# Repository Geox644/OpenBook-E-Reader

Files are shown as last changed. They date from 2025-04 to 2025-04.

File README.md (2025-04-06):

# OpenBook Reader
<br>
Proiectul consta in realizarea unui E-Book Reader accesibil, cu un ecran ce imita hartia, special pentru a avea un consum redus de energie, dar si pentru a oferi utilizatorului o excperinta cat mai placuta. Dispozitivul a fost proiectat de la zero: crearea schemei electrice cu componentele hardware, realizarea 2D PCB + procesul de rutare, trecerea in plan 3D.

<br>

## Diagrama Bloc
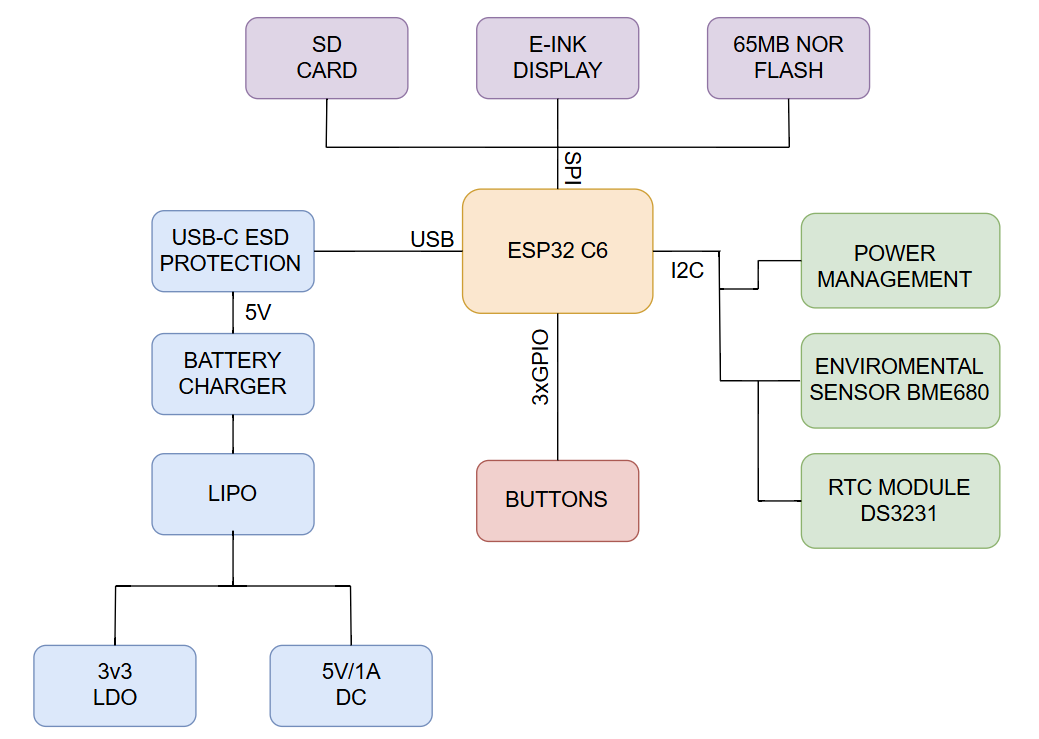
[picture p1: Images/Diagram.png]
Diagrama bloc


<br>

## Descriere functionalitati hardware

### ESP32-C6

* Rol: ESP32-C6 este microcontroller-ul, practic creierul dispozitivului care controleaza toate componentele, gestioneaza si datele.
* Arhitectura: RISC-V 32-bit
* Protocoale: GPIO, I2C, UART, SPI,  PWM
* Memorie:  SD + Flash
* Consum: 10mA (idle), 200mA (WiFi activat)

### MAX17048

* Rol: MAX17048 este monitorul bateriei care vede in timp real nivelul bateriei LiPo si procentul de încarcare.
* Protocol: I2C, SCL: IO6, SDA: IO7

### MCP73831

* Rol: Controloeaza incarcarea eficienta acumulatorul LiPo prin port-ul USB.
* Capacitate: ~500 mA

### XC6204

* Rol: XC6204 reprezinta regulator-ul LDO care reduce tensiunea de la 5V la 3.3V pentru alimentarea sigura a componentelor.

### RTC – DS3231

* Rol: Tine ora exacta chiar si fara alimentare, pentru afisarea corecta a timpului.
* Protocol: I2C, SCL: IO6, SDA: IO7
* Consum: 0.15mA

### BME688 SENSOR

* Rol: Masoara temperatura, umiditatea, etc.
* Protocol: I2C, SCL: IO6, SDA: IO7
* Consum: 3.1mA

### Card SD

* Rol: Salvarea datelor pe dispozitiv.
* Protocol: SPI (pini IO18–IO22)
* Consum: 50mA

### W25Q512JV

* Rol: W25Q512JV este memoria Flash care stocheaza resurse statice folosite de sistemul dispozitivului.
* Protocol: SPI (pini IO18–IO21)
* Consum: 25mA

### Butoane

* Rol: Permite interactiunea manuala a utilizatorului cu dispozitivul.
* Exista 3 tipuri de butoane (Reset, Boot, Change)
* Protocol: GPIO

### E-INK DISPLAY

* Rol: Afisarea continutului/informatiilor de pe dispozitiv. Are un consum redus, deoarece foloseste putine semnale, curentul este necesar atunci cand imaginea se schimba si ramane afisata fara alimentare continua.
* Protocol: GPIO, SPI
* Consum: 40mA

  <br>

## Interfete si pinii de comunicare

| Componente | Interfete | Pini ESP32-C6 |
|---|---|---|
| I2C | BME688, RTC, Battery | SDA (IO22), SCL (IO21) |
| SPI | SD Card, E-paper, NOR Flash | SCK (IO6), MOSI (IO7), MISO (IO2) |
| GPIO | Buttons | IO0 - IO23 |
| USB | Conectare alte dispozitive / incarcare | USB_D+/D- (IO13/IO12) |

<br>

## Observatii

* Modelul 3D al TP-urilor a fost realizat manual de catre mine si au fost pizitionate pe marginea placutei, cat mai aproape de componentele cu care aveau lagaturi
* Au fost facute modificari de footprint pentru U4 – MAX17048G+T10, deoarece alimentarea VBAT a fost proiectata cu o latime de 0.3mm, iar footprint-ul avea o latime a pinilor de 0.27mm.
* Componentele, dimensiunile si pozitiile acestora respecta cat de mult se poate design-ul de referinta.
* ~140 vias PCB
  
<br>

## Bill Of Materials (BOM)

| Componenta | Link | Datasheet |
|---|---|---|
| CAPACITOR 0402 | [Model](https://componentsearchengine.com/part-view/CC0402MRX5R5BB106/YAGEO) | [Datasheet](https://componentsearchengine.com/Datasheets/2/CC0402MRX5R5BB106.pdf) |
| Capacitor 0805| [Model](https://ro.mouser.com/ProductDetail/KYOCERA-AVX/SD0805S020S1R0?qs=jCA%252BPfw4LHbpkAoSnwrdjw%3D%3D) | [Datasheet](https://ro.mouser.com/datasheet/2/40/schottky-3165252.pdf) |
| CPH3225A | [Model](https://www.snapeda.com/parts/CPH3225A/Seiko+Instruments/view-part/?ref=eda) | [Datasheet](https://www.snapeda.com/parts/CPH3225A/Seiko+Instruments/view-part/?ref=eda) |
| RCL CPOL 3528 | [Model](https://www.snapeda.com/parts/TAJB475K025RNJ/AVX/view-part/?ref=dk&t=capacitor%203528&con_ref=None) | [Datasheet](https://s3.amazonaws.com/snapeda/datasheet/TAJB475K025RNJ_AVX.pdf) |
| Resistor 0402 | [Model](https://componentsearchengine.com/part-view/R0402%201%25%20100%20K%20(RC0402FR-07100KL)/YAGEO) | [Datasheet](https://www.yageo.com/upload/media/product/products/datasheet/rchip/PYu-RC_Group_51_RoHS_L_12.pdf) |
| MBR0530 DIODE | [Model](https://eu.mouser.com/ProductDetail/KYOCERA-AVX/SD0805S020S1R0?qs=jCA%252BPfw4LHbpkAoSnwrdjw%3D%3D) | [Datasheet](https://ro.mouser.com/datasheet/2/40/schottky-3165252.pdf) |
| PGB1010603MR DIODE | [Model](https://www.snapeda.com/parts/PGB1010603MR/Littelfuse/view-part/?ref=eda) | [Datasheet](https://www.snapeda.com/parts/PGB1010603MR/Littelfuse%20Inc./datasheet/) |
| BUTTON | [Model](https://industry.panasonic.com/global/en/products/control/switch/light-touch/number/evqpuj02k) | [Datasheet](https://industry.panasonic.com/global/en/downloads?tab=catalog&small_g_cd=203&part_no=EVQPUJ02K) |
| LED 0603 | [Model](https://www.snapeda.com/parts/KP-1608SURCK/Kingbright/view-part/?ref=search&t=LED%200603) | [Datasheet](https://www.snapeda.com/parts/KP-1608SURCK/Kingbright/datasheet/) |
| BME680 Sensor | [Model](https://www.digikey.ro/en/models/7401317) | [Datasheet](https://www.bosch-sensortec.com/media/boschsensortec/downloads/datasheets/bst-bme680-ds001.pdf) |
| SJ | [Model](https://grabcad.com/library/solder-jumpers-1) | [Datasheet](https://grabcad.com/library/solder-jumpers-1) |
| ESP32C6 Varistor 1812 (PFMF) | [Model](https://ro.mouser.com/ProductDetail/EPCOS-TDK/B72520T0350K062?qs=dEfas%2FXlABIszF52uu7vrg%3D%3D) | [Datasheet](https://www.snapeda.com/parts/RC0603JR-070RL/Yageo/datasheet/) |
| FH34SRJ-24S-0.5SH (J1) | [Model](https://www.snapeda.com/parts/FH34SRJ-24S-0.5SH(99)/Hirose/view-part/) | [Datasheet](https://www.snapeda.com/parts/FH34SRJ-24S-0.5SH(99)/Hirose%20Connector/datasheet/) |
| USB4110-GF-A (J2) | [Model](https://componentsearchengine.com/part-view/USB4110-GF-A/GCT%20(GLOBAL%20CONNECTOR%20TECHNOLOGY)) | [Datasheet](https://gct.co/files/drawings/usb4110.pdf) |
| QWIIC Connector (J3) | [Model](https://www.snapeda.com/parts/PRT-14417/SparkFun/view-part/) | [Datasheet](https://www.snapeda.com/parts/PRT-14417/SparkFun%20Electronics/datasheet/) |
| 112A-TAAR-R03 (J4)| [Model](https://www.snapeda.com/parts/112A-TAAR-R03/Attend/view-part/) | [Datasheet](https://www.snapeda.com/parts/112A-TAAR-R03/Attend/datasheet/) |
| 744043680 (L1)| [Model](https://ro.mouser.com/ProductDetail/Wurth-Elektronik/744043680?qs=PGXP4M47uW6VkZq%252BkzjrHA%3D%3D) | [Datasheet](https://www.we-online.com/components/products/datasheet/744043680.pdf) |
| DMG2305UX-7 (Q1&Q2) | [Model](https://componentsearchengine.com/part-view/DMG2305UX-7/Diodes%20Incorporated) | [Datasheet](https://www.snapeda.com/parts/SI1308EDL-T1-GE3/Vishay%20Siliconix/datasheet/) |
| SI1308EDL-T1-GE3 (Q3) | [Model](https://componentsearchengine.com/part-view/SI1308EDL-T1-GE3/Vishay) | [Datasheet](https://www.snapeda.com/parts/SI1308EDL-T1-GE3/Vishay%20Siliconix/datasheet/) |
| W25Q512JVEIQ (U1) | [Model](https://www.snapeda.com/parts/W25Q512JVEIQ/Winbond+Electronics/view-part/?ref=eda) | [Datasheet](https://www.winbond.com/resource-files/W25Q512JV%20SPI%20RevB%2006252019%20KMS.pdf) |
| ESP32C6 WROOM-1-N8 (U2) | [Model](https://www.snapeda.com/parts/ESP32-C6-WROOM-1-N8/Espressif+Systems/view-part/?ref=eda) | [Datasheet](https://www.snapeda.com/parts/ESP32-C6-WROOM-1-N8/Espressif+Systems/view-part/?ref=eda) |
| DS3231SN (U3) | [Model](https://www.snapeda.com/parts/DS3231SN%23/Analog+Devices/view-part/?ref=eda) | [Datasheet](https://www.snapeda.com/parts/DS3231SN%23/Analog%20Devices/datasheet/) |
| MAX17048G+T10 (U4) | [Model](https://www.snapeda.com/parts/MAX17048G+T10/Analog+Devices/view-part/?ref=eda) | [Datasheet](https://www.snapeda.com/parts/MAX17048G+T10/Analog%20Devices/datasheet/) |
| MCP73831 Power Management (U5) | [Model](https://www.snapeda.com/parts/MCP73831T-2ACI/OT/Microchip/view-part/) | [Datasheet](https://www.snapeda.com/parts/MCP73831T-2ACI/OT/Microchip/datasheet/) |
| BD5229G-TR (IC1) | [Model](https://www.digikey.ee/en/models/658502) | [Datasheet](https://fscdn.rohm.com/en/products/databook/datasheet/ic/power/voltage_detector/bd52xxg-e.pdf) |
| XC6220A331MR-G (IC4) | [Model](https://componentsearchengine.com/part-view/XC6220A331MR-G/Torex) | [Datasheet](https://product.torexsemi.com/system/files/series/xc6220.pdf) |

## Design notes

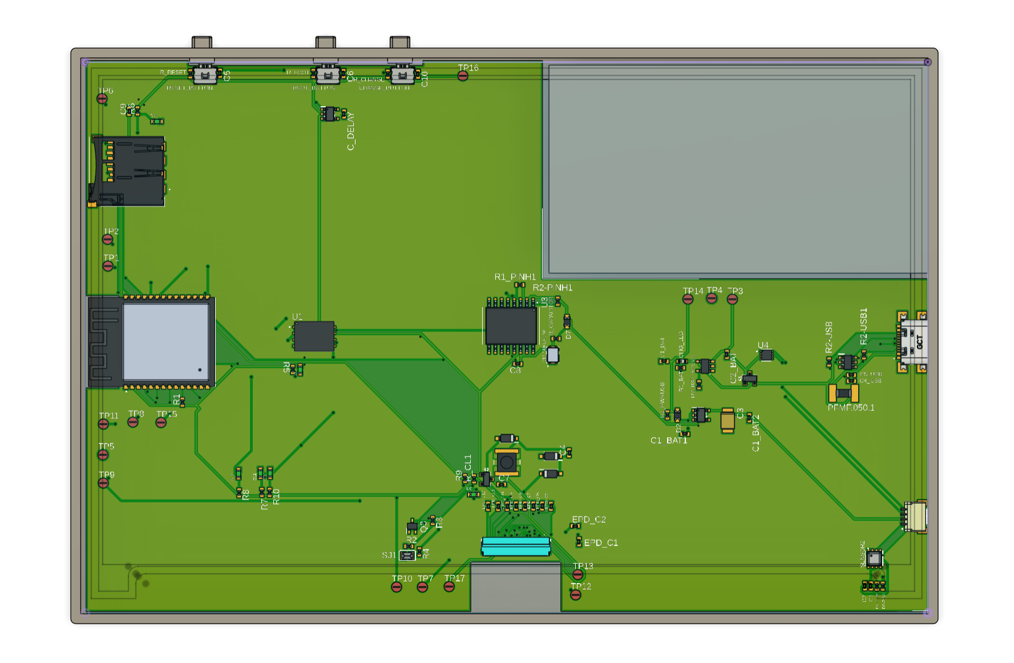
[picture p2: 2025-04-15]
Images/OpenBook_Top.png

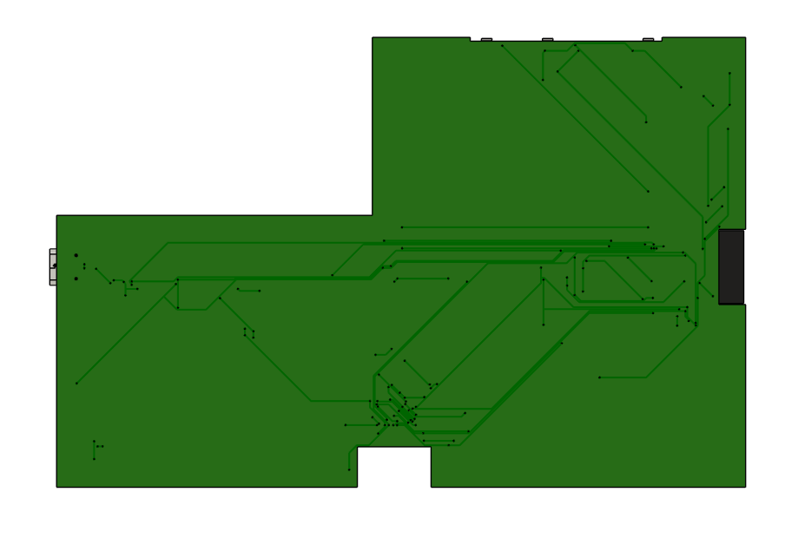
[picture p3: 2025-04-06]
Images/PCB_Bottom.png

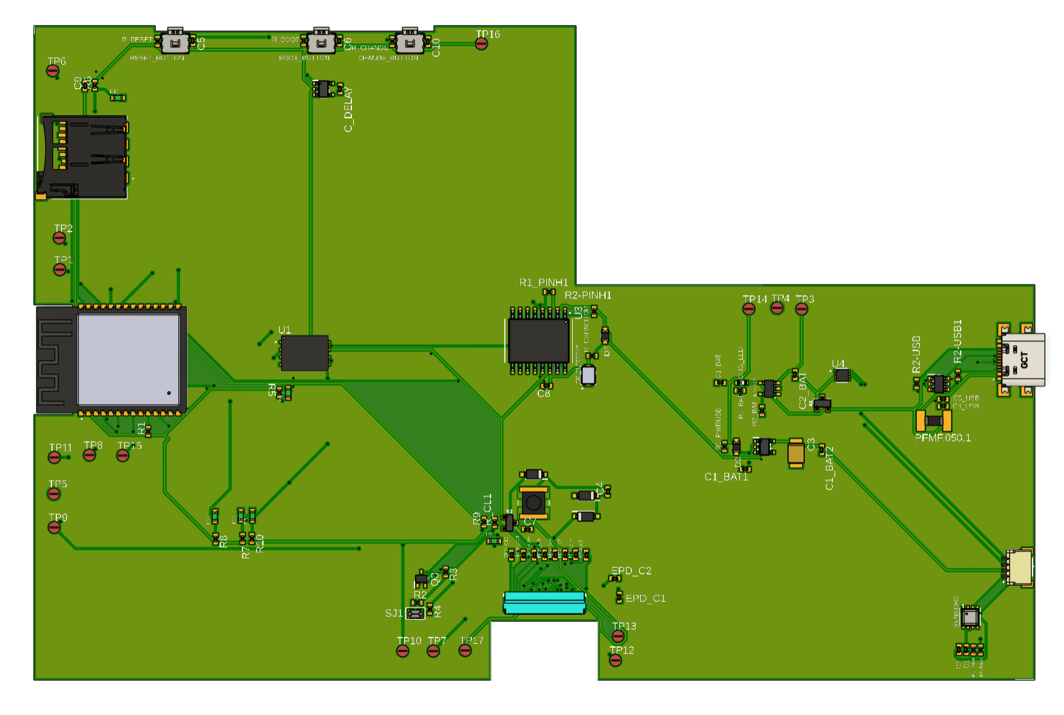
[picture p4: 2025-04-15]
Images/PCB_Top.png

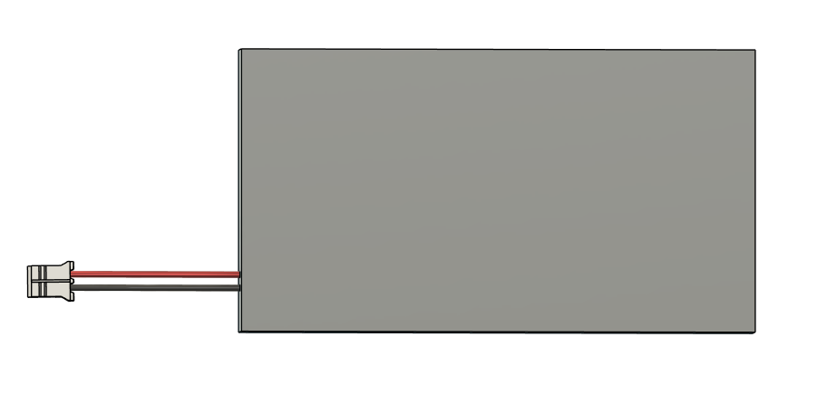
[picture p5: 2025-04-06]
Images/Baterie_Front.png

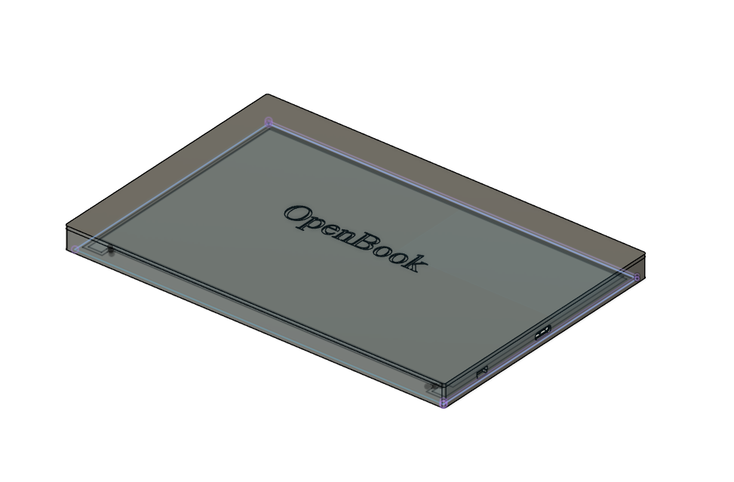
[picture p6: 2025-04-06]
Images/OpenBook_eReader.png

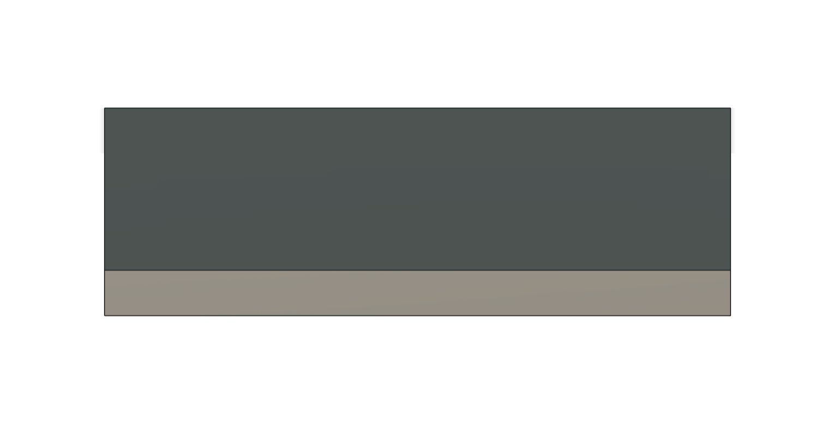
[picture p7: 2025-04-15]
Images/newBattery.png

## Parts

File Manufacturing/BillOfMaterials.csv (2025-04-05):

Qty | Value | Device | Package | Parts | Description | ARROW_PART_NUMBER | ARROW_PRICE-STOCK | AVAILABILITY | CHECK_PRICES | COPYRIGHT | DESCRIPTION | HEIGHT | MANUFACTURER_NAME | MANUFACTURER_PART_NUMBER | MF | MFR_NAME | MOUSER_PART_NUMBER | MOUSER_PRICE-STOCK | MOUSER_TESTING_PART_NUMBER | MOUSER_TESTING_PRICE-STOCK | MP | PACKAGE | POPULARITY | PRICE | PROD_ID | PURCHASE-URL | SNAPEDA_LINK | SPICEPREFIX | VALUE
1 |  | ADAFRUIT_LEDCHIP-LED0603 | ADAFRUIT_CHIP-LED0603 | CHG_LED | LED
1 |  | SJ | SJ | SJ1 | SMD solder JUMPER |  |  |  |  |  |  |  |  |  |  |  |  |  |  |  |  |  | 3
1 | 0.1uF/50V | ESP32_WROVER_EAGLE-LTSPICE_C | ESP32_WROVER_EAGLE-LTSPICE_C0402 | EPD_C5 | CAPACITOR, European symbol
1 | 0.47 | ESP32_WROVER_EAGLE-LTSPICE_R1 | ESP32_WROVER_EAGLE-LTSPICE_C0402 | R3 | RESISTOR, European symbol
1 | 100K | ESP32_WROVER_EAGLE-LTSPICE_R1 | ESP32_WROVER_EAGLE-LTSPICE_C0402 | R1_PWRUSB | RESISTOR, European symbol
8 | 100nF | ESP32_WROVER_EAGLE-LTSPICE_C | ESP32_WROVER_EAGLE-LTSPICE_C0402 | C1, C2, C4_USB, C6, C8, C9, C10, C_DELAY | CAPACITOR, European symbol
1 | 100uF TANT | RCL_CPOL-EUCT3528 | RCL_CT3528 | C3 | POLARIZED CAPACITOR, European symbol |  |  |  |  |  |  |  |  |  |  |  |  |  |  |  |  |  | 0 |  |  |  |  | C
16 | 10K | ESP32_WROVER_EAGLE-LTSPICE_R1 | ESP32_WROVER_EAGLE-LTSPICE_C0402 | R1, R1-PINH, R1_PINH1, R2-PINH, R2-PINH1, R4, R5, R6, R7, R8, R9, R10, R_BOOT, R_CHANGE, R_CL1, R_RESET | RESISTOR, European symbol
1 | 10uF | ESP32_WROVER_EAGLE-LTSPICE_C | ESP32_WROVER_EAGLE-LTSPICE_C0402 | C7 | CAPACITOR, European symbol
1 | 112A-TAAR-R03_ATTEND | 112A-TAAR-R03_ATTEND | 112ATAARR03ATTEND | J4 | Micro SD Card Socket, Push-Push Type, Top Mount, SMT, H=1.83mm, 10u |  |  |  |  |  | Micro SD Card Socket | Push-Push Type | Top Mount | SMT | H=1.83mm | 10u | 1.9mm | ATTEND | 112A-TAAR-R03 ATTEND
1 | 15 | ESP32_WROVER_EAGLE-LTSPICE_R1 | ESP32_WROVER_EAGLE-LTSPICE_C0402 | R_CAPACITOR | RESISTOR, European symbol
1 | 1uF | ESP32_WROVER_EAGLE-LTSPICE_C | ESP32_WROVER_EAGLE-LTSPICE_C0402 | C5 | CAPACITOR, European symbol
9 | 1uF/50V | ESP32_WROVER_EAGLE-LTSPICE_C | ESP32_WROVER_EAGLE-LTSPICE_C0402 | EPD_C1, EPD_C2, EPD_C6, EPD_C7, EPD_C8, EPD_C9, EPD_C10, EPD_C11, EPD_C12 | CAPACITOR, European symbol
1 | 2.2 | ESP32_WROVER_EAGLE-LTSPICE_R1 | ESP32_WROVER_EAGLE-LTSPICE_C0402 | R2 | RESISTOR, European symbol
1 | 200 | ESP32_WROVER_EAGLE-LTSPICE_R1 | ESP32_WROVER_EAGLE-LTSPICE_C0402 | R1_BAT | RESISTOR, European symbol
2 | 20V/4.2A/52mO/1.4W | ESP32_WROVER_SPARKFUN-DISCRETESEMI_MOSFET_PCH | ESP32_WROVER_SPARKFUN-DISCRETESEMI_SOT23-3 | Q1, Q2 | P-channel MOSFETs
1 | 2K | ESP32_WROVER_EAGLE-LTSPICE_R1 | ESP32_WROVER_EAGLE-LTSPICE_C0402 | R2_BAT | RESISTOR, European symbol
5 | 4.7uF | ESP32_WROVER_EAGLE-LTSPICE_C | ESP32_WROVER_EAGLE-LTSPICE_C0402 | C1_BAT, C1_BAT1, C1_BAT2, C2_BAT, C5_USB | CAPACITOR, European symbol
1 | 4.7uF/25V | ESP32_WROVER_EAGLE-LTSPICE_C | ESP32_WROVER_EAGLE-LTSPICE_C0402 | C4 | CAPACITOR, European symbol
2 | 5k1 | ESP32_WROVER_EAGLE-LTSPICE_R1 | ESP32_WROVER_EAGLE-LTSPICE_C0402 | R2-USB, R2-USB1 | RESISTOR, European symbol
1 | 68uH | 744043680IND_4828-WE-TPC_WRE | IND_4828-WE-TPC_WRE | L1 |  |  |  |  |  | Copyright (C) 2024 Ultra Librarian. All rights reserved. |  |  |  | 744043680 |  | Wurth Electronics
1 | BD5229G-TR | BD5229G-TR | SOT95P280X125-5N | IC1 | Voltage Detector with Adjustable Delay Time: CMOS processes are utilized to develop high precision, low current consumption CMOS reset ICs that allow arbitrary setting of the delay time. The extensive lineup includes both Nch Open Drain and CMOS output types in a wide range of detection voltages (from 2.3V to 6.0V, in 0.1V steps), enabling selection of the ideal solution based on customer requirements. In addition, the entire series is of course both lead-free and RoHS-compliant. |  |  |  |  |  | Voltage Detector with Adjustable Delay Time: CMOS processes are utilized to develop high precision | low current consumption CMOS reset ICs that allow arbitrary setting of the delay time. The extensive lineup includes both Nch Open Drain and CMOS output types in a wide range of detection voltages (from 2.3V to 6.0V | in 0.1V steps) | enabling selection of the ideal solution based on customer requirements. In addition | the entire series is of course both lead-free and RoHS-compliant. | 1.25mm | ROHM Semiconductor | BD5229G-TR |  |  | 755-BD5229G-TR | https://www.mouser.co.uk/ProductDetail/ROHM-Semiconductor/BD5229G-TR?qs=4kLU8WoGk0vvnhrrYwdszw%3D%3D
3 | BUTTON_CUSYOMV11 | BUTTON_CUSYOMV11 | MYBUTTON | BOOT_BUTTON, CHANGE_BUTTON, RESET_BUTTON
1 | CPH3225A | CPH3225A | CAPCP3225X100N | C10_SUPERCAP | Cap 0.011F 3.3V 1210 Flat Check availability |  |  | Not in stock | https://www.snapeda.com/parts/CPH3225A/Seiko+Instruments/view-part/?ref=eda |  | 11 mF (EDLC) Supercapacitor 3.3 V 1210 (3225 Metric) - - |  |  |  | Seiko Instruments |  |  |  |  |  | CPH3225A | 1210 Seiko |  | None |  | https://www.snapeda.com/api/url_track_click_mouser/?unipart_id=562593&manufacturer=Seiko Instruments&part_name=CPH3225A&search_term=None | https://www.snapeda.com/parts/CPH3225A/Seiko+Instruments/view-part/?ref=snap
1 | DS3231SN# | DS3231SN# | SOIC127P1032X265-16N | U3 | Real Time Clock Serial 16-Pin SOIC W T/R Check availability |  |  | In Stock | https://www.snapeda.com/parts/DS3231SN%23/Analog+Devices/view-part/?ref=eda |  | Extremely Accurate I²C-Integrated RTC/TCXO/Crystal |  |  |  | Analog Devices |  |  |  |  |  | DS3231SN# | SOIC-16 Maxim |  | None |  | https://www.snapeda.com/api/url_track_click_mouser/?unipart_id=99048&manufacturer=Analog Devices&part_name=DS3231SN#&search_term=None | https://www.snapeda.com/parts/DS3231SN%23/Analog+Devices/view-part/?ref=snap
1 | ESP32-C6-WROOM-1-N8 | ESP32-C6-WROOM-1-N8 | XCVR_ESP32-C6-WROOM-1-N8 | U2 | Check availability |  |  | In Stock | https://www.snapeda.com/parts/ESP32-C6-WROOM-1-N8/Espressif+Systems/view-part/?ref=eda |  | Multiprotocol Modules ESP32-C6 module | Wi-Fi 6 in 2.4 GHz band | Bluetooth 5 | Zigbee 3.0 and Thread. ESP34-WROOM Compatible - ENGINEERING SAMPLE |  |  |  | Espressif Systems |  |  |  |  |  | ESP32-C6-WROOM-1-N8 | None |  | None
1 | ESP32C6_VARISTORCN1812 | ESP32C6_VARISTORCN1812 | ESP32C6_VARISTOR_CT/CN1812 | PFMF.050.1 | VARISTOR |  |  |  |  |  |  |  |  |  |  |  |  |  |  |  |  |  | 0
2 | ESP32_WROVER_AVX---SD0805S020S1R0_AVX_SD0805S020S1R0_0_0 | ESP32_WROVER_AVX---SD0805S020S1R0_AVX_SD0805S020S1R0_0_0 | ESP32_WROVER_AVX---SD0805S020S1R0_AVX_SD0805S020S1R0_0 | D2, D7 | Schottky Barrier Rectifier Diode
1 | ESP32_WROVER_BME680_BME680 | ESP32_WROVER_BME680_BME680 | ESP32_WROVER_BME680_PSON80P300X300X100-8N | SENSOR2 | Integrated Environmental Unit |  |  | Unavailable |  |  | Integrated Environmental Unit |  |  |  | Bosch Sensortec |  |  |  |  |  | BME680 | LGA-8 Bosch Tools |  | None
1 | ESP32_WROVER_SPARKFUN-IC-POWER_MCP73831 | ESP32_WROVER_SPARKFUN-IC-POWER_MCP73831 | ESP32_WROVER_SPARKFUN-IC-POWER_SOT23-5 | MCP73831 | MCP73831T Li-Ion, Li-Pol Controller |  |  |  |  |  |  |  |  |  |  |  |  |  |  |  |  |  |  |  | IC-09995
1 | FH34SRJ-24S-0.5SH_99_ | FH34SRJ-24S-0.5SH_99_ | FH34SRJ24S05SH99 | J1 | (0.50mm) Surface Mount, Right Angle |  |  |  |  |  | 24 Position FFC | FPC Connector Contacts | (0.50mm) Surface Mount | Right Angle | 1.1mm | Hirose | FH34SRJ-24S-0.5SH(99) |  |  | 798-FH34SRJ24S05SH99 | https://www.mouser.co.uk/ProductDetail/Hirose-Connector/FH34SRJ-24S-0.5SH99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
1 | MAX17048G+T10 | MAX17048G+T10 | SON50P200X200X80-9N | U4 | Check availability |  |  | In Stock | https://www.snapeda.com/parts/MAX17048G+T10/Analog+Devices/view-part/?ref=eda |  | 3µA 1-Cell/2-Cell Fuel Gauge with ModelGauge |  |  |  | Analog Devices |  |  |  |  |  | MAX17048G+T10 | TDFN-8 Maxim |  | None |  | https://www.snapeda.com/api/url_track_click_mouser/?unipart_id=329239&manufacturer=Analog Devices&part_name=MAX17048G+T10&search_term=None | https://www.snapeda.com/parts/MAX17048G+T10/Analog+Devices/view-part/?ref=snap
3 | MBR05301 | MBR05301 | SOD3716X135N | D3, D4, D5 | ON SEMICONDUCTOR - MBR0530 - DIODE, SCHOTTKY, 0.5A, 30V, SOD-123
6 | PGB1010603MR1 | PGB1010603MR1 | DIOC1608X36N | D6, D8, D9, D10, D11, D12 | Check availability
1 | QWIIC_RIGHT_ANGLE | QWIIC_CONNECTORJS-1MM | JST04_1MM_RA | J3 | SparkFun I2C Standard Qwiic Connector |  |  |  |  |  |  |  |  |  |  |  |  |  |  |  |  |  |  |  | CONN-13694 |  |  |  | QWIIC_RIGHT_ANGLE
1 | SAMACSYS_PARTS_USB4110-GF-A | SAMACSYS_PARTS_USB4110-GF-A | SAMACSYS_PARTS_USB4110GFA | J2 | CONN USB 2.0 TYPE-C R/A SMT |  |  |  |  |  | CONN USB 2.0 TYPE-C R/A SMT | 3.26mm | GCT (GLOBAL CONNECTOR TECHNOLOGY) | USB4110-GF-A |  |  | 640-USB4110-GF-A | https://www.mouser.co.uk/ProductDetail/GCT/USB4110-GF-A?qs=KUoIvG%2F9IlYiZvIXQjyJeA%3D%3D
1 | SI1308EDL-T1-GE3 | SI1308EDL-T1-GE3 | SOT65P210X110-3N | Q3 | MOSFET N-Ch 30V 1.5A TrenchFET SC70 Vishay Si1308EDL-T1-GE3 N-channel MOSFET Transistor, 1.5 A, 30 V, 3-Pin SC-70 |  |  | In Stock | https://www.snapeda.com/parts/SI1308EDL-T1-GE3/Vishay+Siliconix/view-part/?ref=eda |  | Si1308EDL-T1-GE3 N-channel MOSFET Transistor | 1.5 A | 30 V | 3-Pin SC-70 | Siliconix / Vishay SI1308EDL-T1-GE3 |  |  |  | Vishay Siliconix |  |  |  |  |  | SI1308EDL-T1-GE3 | SOT-323 Vishay Semiconductor |  | None |  | https://www.snapeda.com/api/url_track_click_mouser/?unipart_id=274603&manufacturer=Vishay Siliconix&part_name=SI1308EDL-T1-GE3&search_term=None
17 | TP | TP | TP20R | TP1, TP2, TP3, TP4, TP5, TP6, TP7, TP8, TP9, TP10, TP11, TP12, TP13, TP14, TP15, TP16, TP17 | Test pad
1 | USBLC6-2SC6Y | USBLC6-2SC6Y | SOT95P280X145-6N | D1 | Low Cap. ESD Protection Auto SOT-23-6 STMicroelectronics USBLC6-2SC6Y, Dual Uni-Directional TVS Diode Array, 6-Pin SOT-23 |  |  | In Stock | https://www.snapeda.com/parts/USBLC6-2SC6Y/STMicroelectronics/view-part/?ref=eda |  | 17V Clamp 5A (8/20µs) Ipp Tvs Diode Surface Mount SOT-23-6 |  |  |  | STMicroelectronics |  |  |  |  |  | USBLC6-2SC6Y | SOT-23-6 STMicroelectronics |  | None |  |  | https://www.snapeda.com/parts/USBLC6-2SC6Y/STMicroelectronics/view-part/?ref=snap
1 | W25Q512JVEIQ | W25Q512JVEIQ | SON127P600X800X80-9N | U1 | Check availability |  |  | In Stock | https://www.snapeda.com/parts/W25Q512JVEIQ/Winbond+Electronics/view-part/?ref=eda |  | FLASH - NOR Memory IC 512Mb (64M x 8) SPI - Quad I/O 133 MHz 8-WSON (8x6) |  |  |  | Winbond Electronics |  |  |  |  |  | W25Q512JVEIQ | Package |  | None |  |  | https://www.snapeda.com/parts/W25Q512JVEIQ/Winbond+Electronics/view-part/?ref=snap
1 | XC6220A331MR-G | XC6220A331MR-G | SOT95P280X120-5N | IC4 | LDO Voltage Regulators |  |  |  |  |  | LDO Voltage Regulators | 1.2mm | Torex | XC6220A331MR-G |  |  | 865-XC6220A331MR-G | https://www.mouser.co.uk/ProductDetail/Torex-Semiconductor/XC6220A331MR-G?qs=AsjdqWjXhJ8ZSWznL1J0gg%3D%3D

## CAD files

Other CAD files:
Mechanical/OpenBook Enclosure.f3z

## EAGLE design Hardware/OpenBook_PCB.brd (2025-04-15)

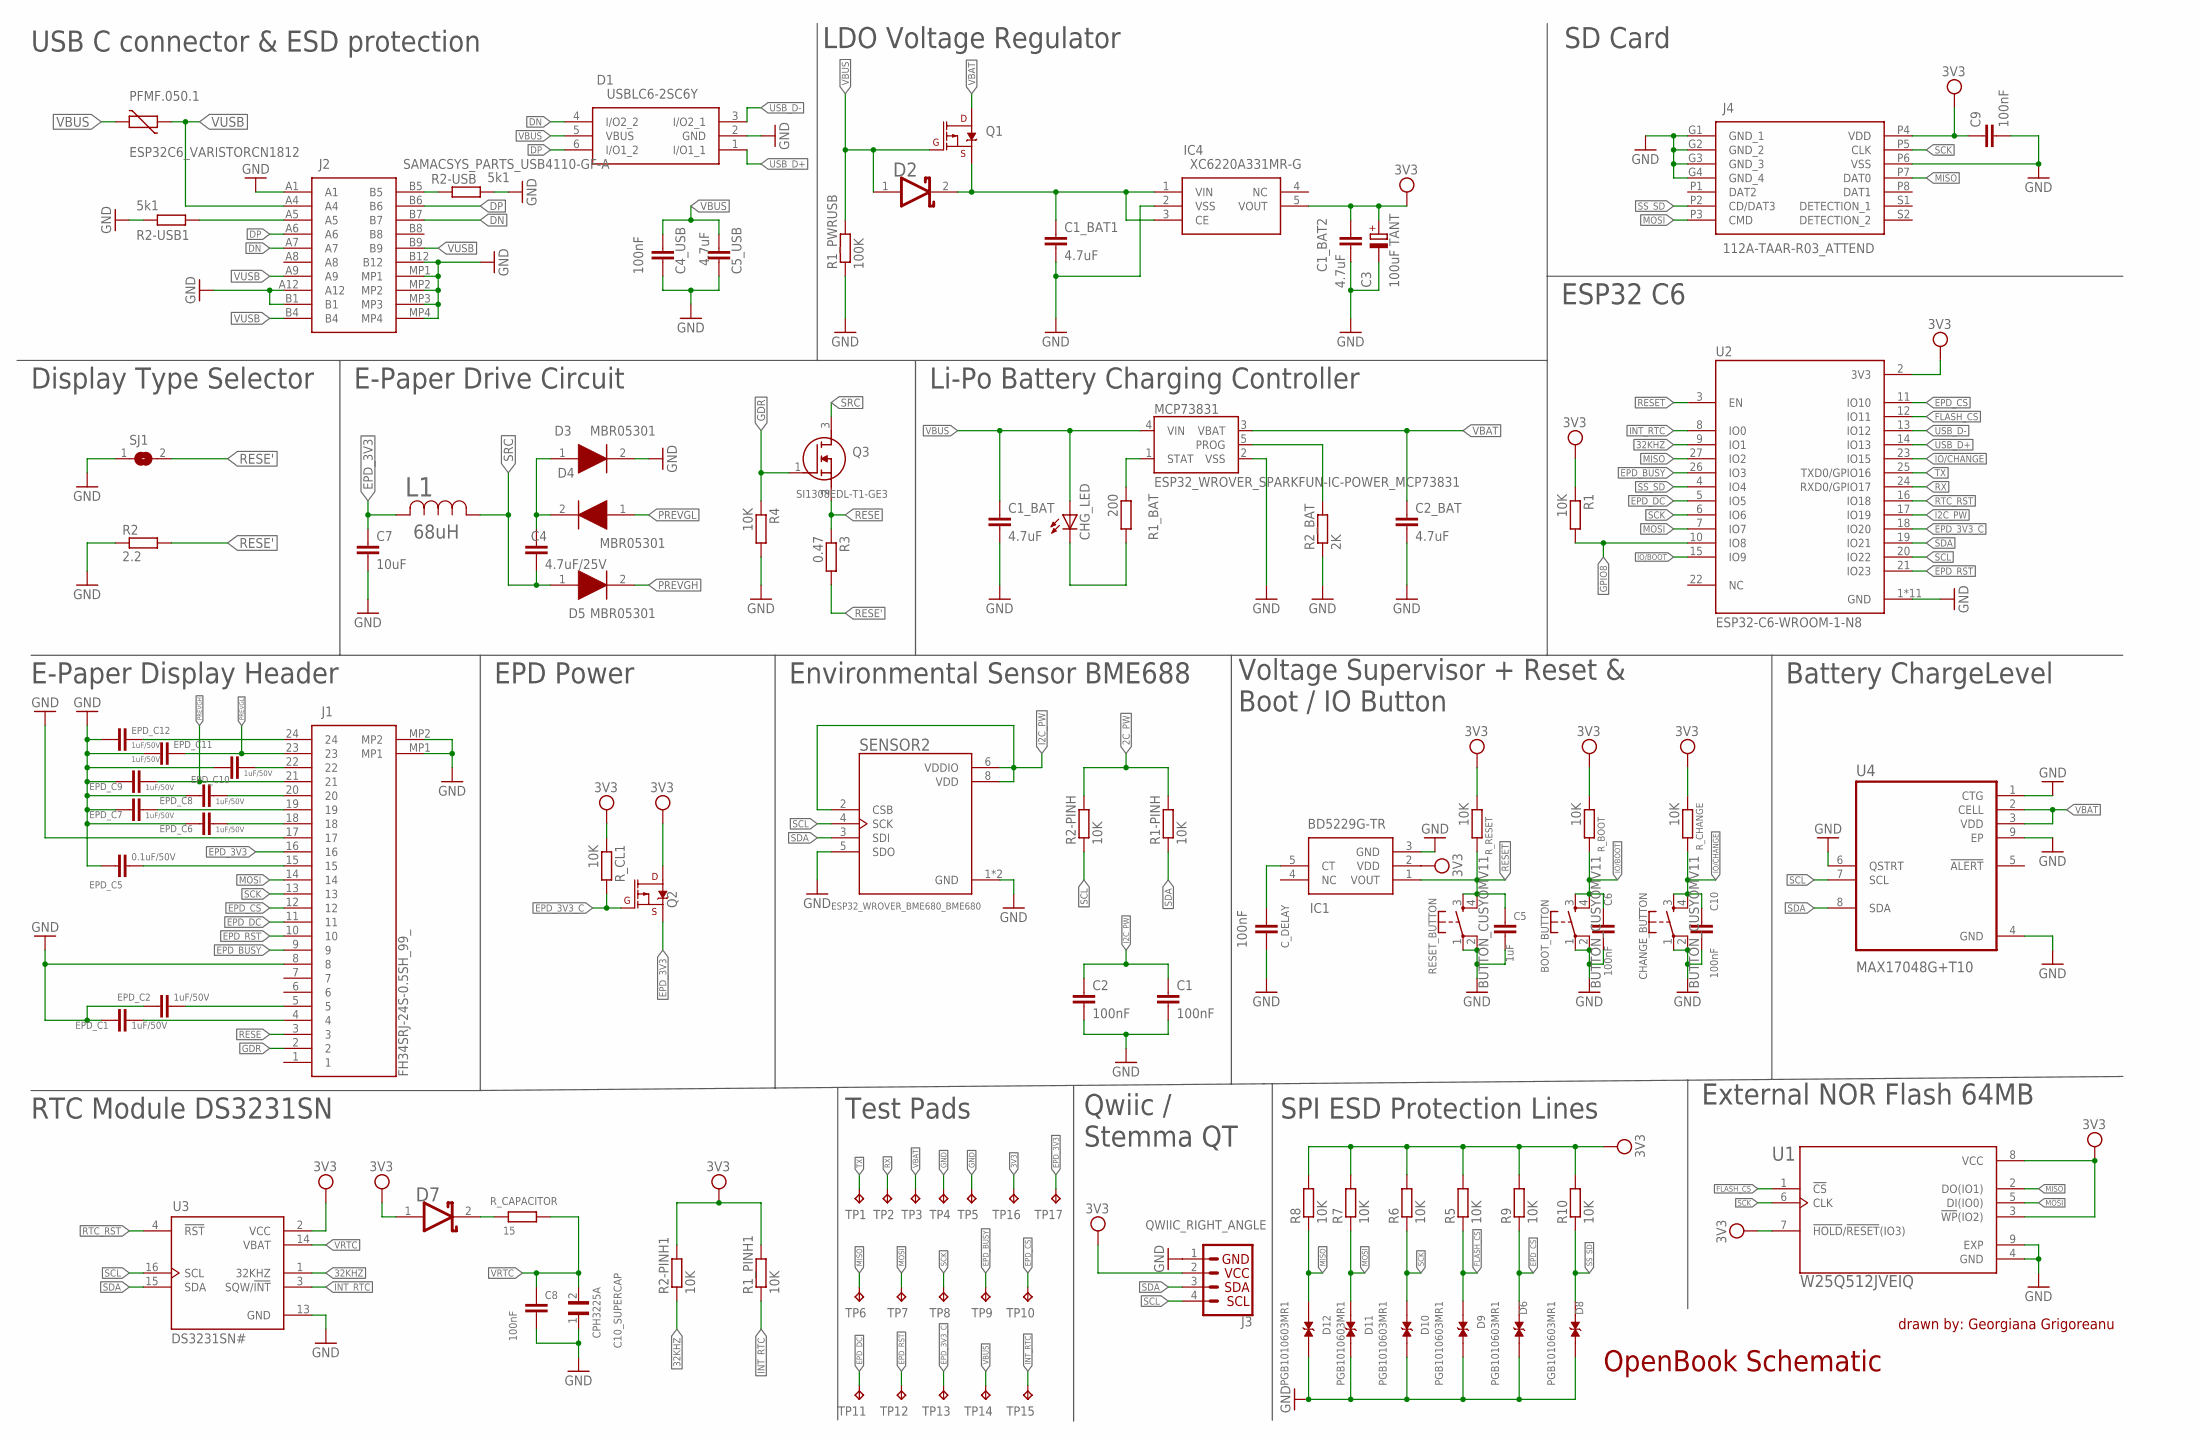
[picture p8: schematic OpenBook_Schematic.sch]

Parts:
BOOT_BUTTON: BUTTON_CUSYOMV11; MYBUTTON
C1, C2, C4_USB, C6, C8, C9, C10: 100nF; ESP32_WROVER_EAGLE-LTSPICE_C0402
C1_BAT, C1_BAT1, C1_BAT2, C2_BAT, C5_USB: 4.7uF; ESP32_WROVER_EAGLE-LTSPICE_C0402
C3: 100uF TANT; RCL_CT3528
C4: 4.7uF/25V; ESP32_WROVER_EAGLE-LTSPICE_C0402
C5: 1uF; ESP32_WROVER_EAGLE-LTSPICE_C0402
C7: 10uF; ESP32_WROVER_EAGLE-LTSPICE_C0402
C10_SUPERCAP: CPH3225A; CAPCP3225X100N
CHANGE_BUTTON: BUTTON_CUSYOMV11; MYBUTTON
CHG_LED: ADAFRUIT_LEDCHIP-LED0603; ADAFRUIT_CHIP-LED0603
C_DELAY: 100nF; ESP32_WROVER_EAGLE-LTSPICE_C0402
D1: USBLC6-2SC6Y; SOT95P280X145-6N
D2, D7: ESP32_WROVER_AVX---SD0805S020S1R0_AVX_SD0805S020S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; ESP32_WROVER_AVX---SD0805S020S1R0_AVX_SD0805S020S1R0_0
D3, D4, D5: MBR05301; SOD3716X135N
D6, D8, D9, D10, D11, D12: PGB1010603MR1; DIOC1608X36N
EPD_C1, EPD_C2, EPD_C6, EPD_C7, EPD_C8, EPD_C9, EPD_C10, EPD_C11, EPD_C12: 1uF/50V; ESP32_WROVER_EAGLE-LTSPICE_C0402
EPD_C5: 0.1uF/50V; ESP32_WROVER_EAGLE-LTSPICE_C0402
IC1: BD5229G-TR; SOT95P280X125-5N
IC4: XC6220A331MR-G; SOT95P280X120-5N
J1: FH34SRJ-24S-0.5SH_99_; FH34SRJ24S05SH99
J2: SAMACSYS_PARTS_USB4110-GF-A; SAMACSYS_PARTS_USB4110GFA
J3: QWIIC_RIGHT_ANGLE; JST04_1MM_RA
J4: 112A-TAAR-R03_ATTEND; 112ATAARR03ATTEND
L1: 68uH; IND_4828-WE-TPC_WRE
MCP73831: ESP32_WROVER_SPARKFUN-IC-POWER_MCP73831; ESP32_WROVER_SPARKFUN-IC-POWER_SOT23-5
PFMF.050.1: ESP32C6_VARISTORCN1812; ESP32C6_VARISTOR_CT/CN1812
Q1, Q2: 20V/4.2A/52mΩ/1.4W; ESP32_WROVER_SPARKFUN-DISCRETESEMI_SOT23-3
Q3: SI1308EDL-T1-GE3; SOT65P210X110-3N
R1, R1-PINH, R1_PINH1, R2-PINH, R2-PINH1, R4, R5, R6, R7, R8, R9, R10: 10K; ESP32_WROVER_EAGLE-LTSPICE_C0402
R1_BAT: 200; ESP32_WROVER_EAGLE-LTSPICE_C0402
R1_PWRUSB: 100K; ESP32_WROVER_EAGLE-LTSPICE_C0402
R2: 2.2; ESP32_WROVER_EAGLE-LTSPICE_C0402
R2-USB, R2-USB1: 5k1; ESP32_WROVER_EAGLE-LTSPICE_C0402
R2_BAT: 2K; ESP32_WROVER_EAGLE-LTSPICE_C0402
R3: 0.47; ESP32_WROVER_EAGLE-LTSPICE_C0402
RESET_BUTTON: BUTTON_CUSYOMV11; MYBUTTON
R_BOOT: 10K; ESP32_WROVER_EAGLE-LTSPICE_C0402
R_CAPACITOR: 15; ESP32_WROVER_EAGLE-LTSPICE_C0402
R_CHANGE: 10K; ESP32_WROVER_EAGLE-LTSPICE_C0402
R_CL1: 10K; ESP32_WROVER_EAGLE-LTSPICE_C0402
R_RESET: 10K; ESP32_WROVER_EAGLE-LTSPICE_C0402
SENSOR2: ESP32_WROVER_BME680_BME680; ESP32_WROVER_BME680_PSON80P300X300X100-8N
SJ1: SJ
TP1, TP2, TP3, TP4, TP5, TP6, TP7, TP8, TP9, TP10, TP11, TP12, TP13, TP14, TP15, TP16, TP17: TP; TP20R
U1: W25Q512JVEIQ; SON127P600X800X80-9N
U2: ESP32-C6-WROOM-1-N8; XCVR_ESP32-C6-WROOM-1-N8
U3: DS3231SN#; SOIC127P1032X265-16N
U4: MAX17048G+T10; SON50P200X200X80-9N

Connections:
2C_PW: R1-PINH.2, R2-PINH.2
3V3: C1_BAT2.1, C3.+, C9.1, D7.1 (ANODE), IC1.2 (VDD), IC4.5 (VOUT), J3.2, J4.P4 (VDD), Q2.1 (D), R1.1, R1_PINH1.2, R2-PINH1.2, R5.2, R6.2, R7.2, R8.2, R9.2, R10.2, R_BOOT.1, R_CHANGE.1, R_CL1.1, R_RESET.1, TP16.TP, U1.3 (!WP!(IO2)), U1.7 (!HOLD!/!RESET!(IO3)), U1.8 (VCC), U2.2 (3V3), U3.2 (VCC)
32KHZ: R2-PINH1.1, U2.9 (IO1), U3.1 (32KHZ)
DN: D1.4 (I/O2_2), J2.A7, J2.B7
DP: D1.6 (I/O1_2), J2.A6, J2.B6
EPD_3V3: C7.1, J1.16, L1.2, Q2.3 (S), TP17.TP
EPD_3V3_C: Q2.2 (G), R_CL1.2, TP13.TP, U2.18 (IO20)
EPD_BUSY: J1.9, TP9.TP, U2.26 (IO3)
EPD_CS: D6.1, J1.12, R9.1, TP10.TP, U2.11 (IO10)
EPD_DC: J1.11, TP11.TP, U2.5 (IO5)
EPD_RST: J1.10, TP12.TP, U2.21 (IO23)
FLASH_CS: D9.1, R5.1, U1.1 (!CS), U2.12 (IO11)
GDR: J1.2, Q3.1 (G), R4.1
GND: BOOT_BUTTON.1, BOOT_BUTTON.2, C1.2, C1_BAT.2, C1_BAT1.2, C1_BAT2.2, C2.2, C2_BAT.2, C3.-, C4_USB.2, C5.2, C5_USB.2, C6.2, C7.2, C8.2, C9.2, C10.2, C10_SUPERCAP.1, CHANGE_BUTTON.1, CHANGE_BUTTON.2, C_DELAY.2, D1.2 (GND), D3.2 (K), D6.2, D8.2, D9.2, D10.2, D11.2, D12.2, EPD_C1.2, EPD_C2.2, EPD_C5.2, EPD_C6.2, EPD_C7.2, EPD_C8.2, EPD_C9.2, EPD_C10.2, EPD_C11.2, EPD_C12.2, IC1.3 (GND), IC4.2 (VSS), J1.8, J1.17, J1.MP1, J1.MP2, J2.A1, J2.A12, J2.B1, J2.B12, J2.MP1, J2.MP2, J2.MP3, J2.MP4, J3.1, J4.G1 (GND_1), J4.G2 (GND_2), J4.G3 (GND_3), J4.G4 (GND_4), J4.P6 (VSS), MCP73831.2 (VSS), R1_PWRUSB.1, R2.1, R2-USB.2, R2-USB1.1, R2_BAT.1, R4.2, RESET_BUTTON.1, RESET_BUTTON.2, SENSOR2.1 (GND), SENSOR2.5 (SDO), SENSOR2.7 (GND), SJ1.1, TP4.TP, TP5.TP, U1.4 (GND), U1.9 (EXP), U2.1 (GND), U2.28 (GND), U2.29_1 (GND), U2.29_2 (GND), U2.29_3 (GND), U2.29_4 (GND), U2.29_5 (GND), U2.29_6 (GND), U2.29_7 (GND), U2.29_8 (GND), U2.29_9 (GND), U3.13 (GND), U4.1 (CTG), U4.4 (GND), U4.6 (QSTRT), U4.9 (EP)
GPIO8: R1.2, U2.10 (IO8)
I2C_PW: C1.1, C2.1, SENSOR2.2 (CSB), SENSOR2.6 (VDDIO), SENSOR2.8 (VDD), U2.17 (IO19)
INT_RTC: R1_PINH1.1, TP15.TP, U2.8 (IO0), U3.3 (SQW/!INT)
IO/BOOT: BOOT_BUTTON.3, BOOT_BUTTON.4, C6.1, R_BOOT.2, U2.15 (IO9)
IO/CHANGE: C10.1, CHANGE_BUTTON.3, CHANGE_BUTTON.4, R_CHANGE.2, U2.23 (IO15)
MISO: D12.1, J4.P7 (DAT0), R8.1, TP6.TP, U1.2 (DO(IO1)), U2.27 (IO2)
MOSI: D11.1, J1.14, J4.P3 (CMD), R7.1, TP7.TP, U1.5 (DI(IO0)), U2.7 (IO7)
unnamed: J2.A5, R2-USB1.2
unnamed: J2.B5, R2-USB.1
unnamed: C1_BAT1.1, D2.2 (CATHODE), IC4.1 (VIN), IC4.3 (CE), Q1.3 (S)
unnamed: MCP73831.1 (STAT), R1_BAT.1
unnamed: CHG_LED.C, R1_BAT.2
unnamed: C4.1, D3.1 (A), D4.2 (K)
unnamed: EPD_C12.1, J1.24
unnamed: MCP73831.5 (PROG), R2_BAT.2
unnamed: EPD_C6.1, J1.18
unnamed: EPD_C7.1, J1.19
unnamed: EPD_C8.1, J1.20
unnamed: C_DELAY.1, IC1.5 (CT)
unnamed: EPD_C10.1, J1.22
unnamed: D7.2 (CATHODE), R_CAPACITOR.2
unnamed: EPD_C5.1, J1.15
unnamed: EPD_C2.1, J1.5
unnamed: EPD_C1.1, J1.4
PREVGH: D5.2 (K), EPD_C9.1, J1.21
PREVGL: D4.1 (A), EPD_C11.1, J1.23
RESE: J1.3, Q3.2 (S), R3.1
RESE': R2.2, R3.2, SJ1.2
RESET: C5.1, IC1.1 (VOUT), RESET_BUTTON.3, RESET_BUTTON.4, R_RESET.2, U2.3 (EN)
RTC_RST: U2.16 (IO18), U3.4 (!RST)
RX: TP2.TP, U2.24 (RXD0/GPIO17)
SCK: D10.1, J1.13, J4.P5 (CLK), R6.1, TP8.TP, U1.6 (CLK), U2.6 (IO6)
SCL: J3.4, R2-PINH.1, SENSOR2.4 (SCK), U2.20 (IO22), U3.16 (SCL), U4.7 (SCL)
SDA: J3.3, R1-PINH.1, SENSOR2.3 (SDI), U2.19 (IO21), U3.15 (SDA), U4.8 (SDA)
SRC: C4.2, D5.1 (A), L1.1, Q3.3 (D)
SS_SD: D8.1, J4.P2 (CD/DAT3), R10.1, U2.4 (IO4)
TX: TP1.TP, U2.25 (TXD0/GPIO16)
USB_D+: D1.1 (I/O1_1), U2.14 (IO13)
USB_D-: D1.3 (I/O2_1), U2.13 (IO12)
VBAT: C2_BAT.1, MCP73831.3 (VBAT), Q1.1 (D), TP3.TP, U4.2 (CELL), U4.3 (VDD)
VBUS: C1_BAT.1, C4_USB.1, C5_USB.1, CHG_LED.A, D1.5 (VBUS), D2.1 (ANODE), MCP73831.4 (VIN), PFMF.050.1.2, Q1.2 (G), R1_PWRUSB.2, TP14.TP
VRTC: C8.1, C10_SUPERCAP.2, R_CAPACITOR.1, U3.14 (VBAT)
VUSB: J2.A4, J2.A9, J2.B4, J2.B9, PFMF.050.1.1

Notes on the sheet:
USB C connector & ESD protection
LDO Voltage Regulator
SD Card
E-Paper Drive Circuit
Display Type Selector
Li-Po Battery Charging Controller
ESP32 C6
E-Paper Display Header
EPD Power
Environmental Sensor BME688
Voltage Supervisor + Reset & Boot / IO Button
Battery ChargeLevel
RTC Module DS3231SN
Test Pads
Qwiic / Stemma QT
SPI ESD Protection Lines
External NOR Flash 64MB
OpenBook Schematic
drawn by: Georgiana Grigoreanu

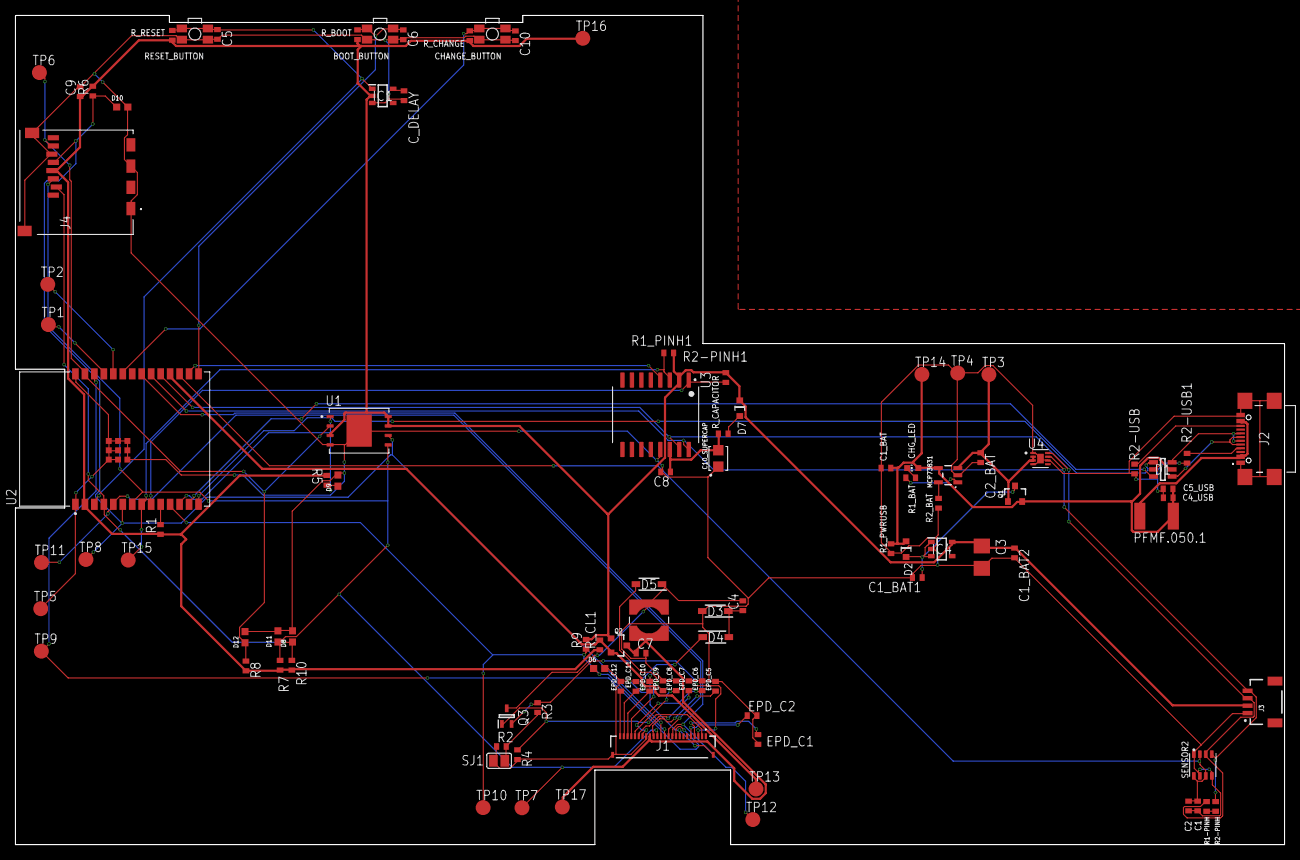
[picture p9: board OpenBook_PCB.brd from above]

Board: 2 copper layers, 170.2 x 111.2 mm, 103 parts (0 on the bottom side), 57 nets.

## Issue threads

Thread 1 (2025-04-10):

fixare warning-uri ERC

biancapintilie, 2025-04-10:
In urma verificarii ERC, au fost identificate urmatoarele avertismente:

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

- **"Part ... has no value"**: Aceste avertismente pot fi ignorate, deoarece schematicul furnizat in cerintele proiectului nu specifica valori concrete.
- **"POWER pin ... connected to ..."**: Conexiunile sunt corecte conform designului si pot fi aprobate.
- **"Net ... overlaps pin"**: Acestea pot fi ajustate pentru a evita suprapunerile si pentru a asigura claritatea vizuala.
- **"Close but unconnected wires ..."**: Acestea necesita corecturi pentru a stabili conexiunile corecte.

Nu au fost identificate erori critice, iar schematicul este, in general, intr-o stare buna.

Closed 2025-04-15.

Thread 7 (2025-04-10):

unghiuri drepte

biancapintilie, 2025-04-10:
Am gasit cateva unghiuri drepte la rutare:
- langa componenta IC4
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

- in zona de sub ESP32
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

- sub butonul de boot
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

Geox644, 2025-04-15:
## Unghiuri drepte rezolvate:
- langa componenta IC4

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

- in zona de sub ESP32

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

- sub butonul de boot

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

Closed 2025-04-15.

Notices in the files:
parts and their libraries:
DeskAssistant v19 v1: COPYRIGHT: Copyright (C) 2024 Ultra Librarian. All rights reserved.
